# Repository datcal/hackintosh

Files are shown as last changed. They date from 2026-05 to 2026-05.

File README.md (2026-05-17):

# Hackintosh

A USB-tethered OLED companion device — Tinytosh-style retro-Mac chrome with live
animations — for showing clock, weather, air quality, currency rates, system
metrics, and now-playing media from your host PC.

## Hardware

- Seeed XIAO RP2040
- 0.96" SSD1306 128x64 I2C OLED at `0x3C`
- 2 momentary push buttons

For full wiring details, pin map, circuit diagram, and 4-pin button anatomy,
see **[docs/HARDWARE.md](docs/HARDWARE.md)**.

## Layout

```
firmware/   Arduino C++ for the XIAO RP2040 — receives 1024-byte framebuffers
            over USB-CDC and blits them; sends button events back.
host/       Go application — fetches data, renders 1-bit 128x64 framebuffers at
            30 FPS, streams them over the serial port.
scripts/    Build scripts (Windows .ps1, macOS .sh) for host + firmware + dev.
dist/       Build outputs (gitignored).
```

## Quick start

**Build the host:**
- Windows: `.\scripts\build-host.ps1`
- macOS:   `./scripts/build-host.sh`

**Build + flash the firmware in one shot** (recommended once your board is alive):
- Windows: `.\scripts\flash-firmware.ps1`
- macOS:   `./scripts/flash-firmware.sh`

This compiles + uploads via the 1200-baud auto-reset trick — no button presses on the board.

**First flash** (or recovery when firmware is unresponsive):
- Build only: `.\scripts\build-firmware.ps1` / `./scripts/build-firmware.sh`
- Then **double-tap the XIAO's RESET** and drag `dist/hackintosh.uf2` onto the `RPI-RP2` drive.

For one-time `arduino-cli` setup and troubleshooting, see **[docs/FLASHING.md](docs/FLASHING.md)**.

**Run without hardware (browser simulator):**
- Windows: `.\scripts\dev-host.ps1 --simulate=:8080`
- macOS:   `./scripts/dev-host.sh --simulate=:8080`

Open <http://localhost:8080> in a browser. You'll see a styled XIAO+OLED device
with the full UI streaming at 30 FPS via Server-Sent Events. The two on-screen
buttons (and keys `A`/`1`, `B`/`2`) feed presses back to the app exactly like
the real hardware. Long-press = hold for 700 ms.

The same flag works on the production binary:
```
dist\hackintosh.exe --simulate=:8080
dist/hackintosh     --simulate=:8080
```

**Probe a connected MCU:** `.\scripts\dev-host.ps1 --probe`

**Flags:** `--no-net` skips weather + currency · `--no-hw` skips system monitor
· `--no-media` skips the now-playing source · `--port=COM5` picks a specific
serial port.

## Install as a startup app

To have the host run automatically when you log in, with a menu-bar / tray
icon instead of a terminal window:

1. Build the host:
   - Windows: `./scripts/build-host.ps1`
   - macOS:   `./scripts/build-host.sh`
   - Linux:   `cd host && go build -o ../dist/hackintosh ./cmd/hackintosh`
2. Run the installer:

   ```
   ./dist/hackintosh install
   ```

   This copies the binary to a per-user location and registers it for
   autostart. No admin/sudo required.
3. The next time you log in, an icon appears in your system tray (Windows)
   or menu bar (macOS) or app tray (Linux). Right-click for: Open Simulator
   (only enabled in simulator mode), Restart, Quit.
4. Re-launch from your Start Menu / Applications folder / app menu after
   quitting, just like any other installed app.

To remove everything the installer added:

```bash
./dist/hackintosh uninstall
```

After making code changes, rebuild and run `./dist/hackintosh install`
again. It is idempotent and overwrites the previous binary.

### Linux note: system trays in GNOME

GNOME removed built-in tray support, so on stock GNOME the icon will not
appear without an extension like AppIndicator or TopIconsPlus. The host
still runs and connects to the device; only the menu is hidden.

### macOS note: Gatekeeper

The first run on macOS Catalina+ may trigger a Gatekeeper warning
("Hackintosh cannot be opened"). Right-click the app in Finder, choose Open,
or run `xattr -d com.apple.quarantine ~/Applications/Hackintosh.app` once.

## Controls

- **Button A** — Tea timer: tap to start a 3-minute countdown, tap again to pause/resume, long-press to reset. "TEA!" appears on the OLED when it expires.
- **Button B** — Cycle to the next screen (Clock → Weather → AQ → Currency → System → Media)
- **A + B together for 3 seconds** — Reboot into bootloader for over-the-USB firmware updates. The OLED briefly shows "BOOTLOAD ready to flash". Pair with `.\scripts\dev-host.ps1 --flash dist\hackintosh.uf2` for fully scripted updates.

## Documentation

- [docs/HARDWARE.md](docs/HARDWARE.md) — wiring, pin map, circuit diagram, button anatomy
- [docs/FLASHING.md](docs/FLASHING.md) — toolchain setup, firmware build, UF2 upload, troubleshooting

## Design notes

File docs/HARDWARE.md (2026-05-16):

# Hardware

Wiring, pin map, and physical assembly for Hackintosh.

## Parts list

| Part | Notes |
|---|---|
| Seeed XIAO RP2040 | The microcontroller. RP2040 chip, USB-C, no WiFi/BT. |
| 0.96" SSD1306 OLED, 128x64, I2C | Adafruit / generic. I2C address `0x3C`. |
| 2 momentary push buttons | 4-pin tactile style works (only 2 of the 4 pins are needed). |
| USB-C cable | Must be a *data* cable — many charge-only cables won't enumerate. |
| Optional: 2 x ~10kΩ resistors | NOT needed when using `INPUT_PULLUP` in firmware. |

## Pin assignments

The XIAO RP2040 has **silkscreen labels** (`D0`–`D10`) which are different from
the internal **GPIO numbers** (`GP0`–`GP29`). When wiring, use the silkscreen
labels — that's what's printed on the board next to each pin.

| Function | Silkscreen | Internal GPIO | Notes |
|---|---|---|---|
| OLED SDA | **D4** | GP6 | I2C data |
| OLED SCL | **D5** | GP7 | I2C clock |
| Button A | **D0** | GP26 | INPUT_PULLUP — buttons short to GND |
| Button B | **D1** | GP27 | INPUT_PULLUP — buttons short to GND |
| OLED VCC | **3V3** | — | 3.3 V supply |
| OLED GND | **GND** | — | shared with button GNDs |

## XIAO RP2040 pinout reference

Looking at the board with the **USB-C connector facing up**:

```
            +-------------+
            |    USB-C    |
            +--+-------+--+
        D0 -- *|       |* -- 5V
        D1 -- *|       |* -- GND
        D2 -- *|       |* -- 3V3
        D3 -- *|  XIAO |* -- D10
        D4 -- *| RP2040|* -- D9
        D5 -- *|       |* -- D8
              |       |* -- D7
              +-------+* -- D6
```

## Circuit diagram

```
                                 SSD1306 OLED 128x64
                                 +----+----+----+----+
                                 |GND |VCC |SCL |SDA |
                                 +-+--+-+--+-+--+-+--+
                                   |    |    |    |
                                   |    |    |    |
                       +-----------+    |    |    +---- to D4 (SDA)
                       |        +-------+    +---- to D5 (SCL)
                       |        |    +---- to 3V3
                       |        |    |
                       |        |    |
                      GND      3V3   |  (already routed via the OLED rail)
                       (shared GND rail with both buttons)

                       +----------------------+
                       |  XIAO RP2040         |
                       |  (USB-C on top)      |
                       |                      |
                  D0 --|                      |-- 5V
                  D1 --|                      |-- GND (shared GND rail)
                  D2 --|                      |-- 3V3 (powers OLED)
                  D3 --|                      |-- D10
                  D4 --| (OLED SDA)           |-- D9
                  D5 --| (OLED SCL)           |-- D8
                       |                      |
                       +----------------------+
                        ^                  ^
                        |                  |
                       D0                 D1
                        |                  |
            +----- BUTTON A -----+   +----- BUTTON B -----+
            |                    |   |                    |
            |  PIN 1 *    * PIN 2|   |  PIN 1 *    * PIN 2|
            |          X         |   |          X         |
            |  PIN 3 *    * PIN 4|   |  PIN 3 *    * PIN 4|
            +----+-----------+---+   +----+-----------+---+
                 |           |            |           |
              (to D0)     (to GND)     (to D1)     (to GND)
                 |           |            |           |
                 +-----------+------------+-----------+
                             |
                             v
                            GND (any GND pin on the XIAO)
```

## 4-pin tactile button anatomy

The 4 pins of a typical tactile button only correspond to **2 electrical
contacts**. Pins on the same side of the body are internally bridged with a
metal bar at all times — even when the button isn't pressed. Pressing the
cap closes a contact between the two sides.

```
          +---------------------+
          |                     |
   PIN 1 *|@           @        |* PIN 2
          |                     |
          |        [cap]        |
          |                     |
   PIN 3 *|@           @        |* PIN 4
          |                     |
          +---------------------+

  Always connected:
    PIN 1 --- PIN 3       (one internal side bar)
    PIN 2 --- PIN 4       (the other internal side bar)

  When pressed, the gap closes — now all four are connected.
```

**Rule of thumb:** pick any pin on the LEFT side and any pin on the RIGHT
side. Those are your "switch terminals." Diagonal (PIN 1 + PIN 4) is the
safest choice because they're guaranteed to be on opposite sides.

If your multimeter shows all 4 pins connected when pressed, your button
is healthy — that's expected behavior.

## How the active-LOW input works

The firmware configures Button A and Button B as `INPUT_PULLUP`. This
activates the RP2040's built-in ~50kΩ pull-up resistor on each GPIO, so:

```
Button NOT pressed:                Button PRESSED:

  3V3 --[ ~50kΩ pull-up ]--+         3V3 --[ ~50kΩ pull-up ]--+
                           |                                  |
                          GPIO  (reads HIGH ~ 3.3V)           GPIO  (reads LOW ~ 0V)
                           |                                  |
                          (open switch)                      (closed switch)
                           |                                  |
                          GND                                GND
```

In firmware (see `buttons.cpp`), `digitalRead(pin) == LOW` means "pressed."

## Why you don't need the external resistors

If your buttons came bundled with separate resistors, they were intended
for the **external pull-up** wiring pattern: GPIO -> 10kΩ -> 3V3, plus GPIO ->
button -> GND. With `INPUT_PULLUP` in firmware, the resistor is internal —
the external one becomes redundant.

You can wire the externals too if you want — it doesn't hurt, just makes the
input slightly stiffer against electrical noise. To use the externals
instead of the internal pull-up, change `INPUT_PULLUP` to `INPUT` in
`firmware/hackintosh/buttons.cpp:begin()`.

## Display orientation (mounting it upside-down)

If you physically mount the OLED upside-down, set this in
`firmware/hackintosh/config.h`:

```cpp
constexpr bool OLED_FLIP_180 = true;
```

This sends two override commands to the SSD1306 during init (`SEGREMAP` +
`COMSCANINC`) that rotate the display 180° in hardware. The host doesn't
need to know — every screen, splash, and animation comes out the right way
up. Set it back to `false` if you flip the mounting.

## Power budget

| Component | Typical | Max |
|---|---|---|
| RP2040 idle | ~15 mA | ~50 mA |
| SSD1306 OLED, all pixels off | ~5 mA | — |
| SSD1306 OLED, all pixels on | — | ~25 mA |
| Total at typical usage | ~25 mA | ~75 mA |

All well under USB's 500 mA budget. No need for an external supply.

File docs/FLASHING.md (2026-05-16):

# Flashing the firmware

How to compile and upload the Arduino firmware to your XIAO RP2040.

The RP2040 uses **UF2 (USB Flashing Format)**, which means you don't need
`avrdude`, `esptool`, or any traditional uploader — you just **copy a file
onto a USB drive that appears when you put the board into bootloader mode**.

Three ways to do it, in order of how nice they are once your firmware is
working:

1. **Hold A+B on the device for 3 seconds, then auto-copy from Go** —
   the cleanest path. Your application buttons trigger the reboot, the Go
   tool watches for the bootloader drive and copies the new firmware over.
   Zero physical RESET/BOOT button presses, fully scripted, works on
   Windows + macOS + Linux. See "Option 0" below.
2. **`arduino-cli` 1200-baud auto-upload** — works if your firmware is
   running and responsive. Compile + upload in one script.
3. **Manual double-tap RESET** — required for the very first flash (before
   any firmware exists) or if your current firmware is unresponsive.

## One-time toolchain setup

The Go host doesn't need anything beyond Go itself, but the firmware needs
the Arduino CLI plus the RP2040 board package and two display libraries.

```powershell
# 1. Install arduino-cli
winget install ArduinoSA.CLI
# (on macOS:  brew install arduino-cli)

# 2. Add the community RP2040 board package (Earle Philhower's core)
arduino-cli core update-index --additional-urls https://github.com/earlephilhower/arduino-pico/releases/download/global/package_rp2040_index.json
arduino-cli core install rp2040:rp2040 --additional-urls https://github.com/earlephilhower/arduino-pico/releases/download/global/package_rp2040_index.json

# 3. Install the OLED libraries
arduino-cli lib install "Adafruit GFX Library" "Adafruit SSD1306"
```

To verify the install succeeded:

```powershell
arduino-cli core list
# Should list:  rp2040:rp2040  <version>  arduino-pico

arduino-cli board listall xiao
# Should list:  Seeed XIAO RP2040  rp2040:rp2040:seeed_xiao_rp2040
```

The RP2040 board package is ~150 MB (it bundles a full GCC cross-compiler
for ARM Cortex-M0+). This is a one-time download.

## Build the .uf2

From the project root:

```powershell
.\scripts\build-firmware.ps1
```

On macOS / Linux:

```bash
./scripts/build-firmware.sh
```

This invokes `arduino-cli compile` with the right FQBN (`rp2040:rp2040:seeed_xiao_rp2040`),
compiles all the `.ino` and `.cpp` files under `firmware/hackintosh/`,
and writes `dist/hackintosh.uf2`.

Typical output size: 30–80 KB.

## Option 0 — A+B hold (3 sec) + Go auto-copy (recommended)

This is the smoothest workflow once the device is alive. The XIAO's tiny
on-board RESET and BOOT buttons are never touched.

### How it works

1. The firmware watches both application buttons (A on D0, B on D1). When
   it sees them held simultaneously for **3 seconds**, it briefly draws a
   "BOOTLOAD ready to flash" panel on the OLED, then calls
   `rp2040.rebootToBootloader()` — a soft reset into the mask-ROM bootloader.
2. The `RPI-RP2` mass-storage drive appears on your computer within ~500ms.
3. The Go host's `--flash` mode polls for that drive cross-platform
   (checking for the `INFO_UF2.TXT` marker file the bootloader always
   writes) and copies your new `dist\hackintosh.uf2` onto it.
4. The bootloader detects the .uf2 write, flashes it to internal flash, and
   reboots into the new firmware. Total elapsed: ~5-8 seconds.

### Step by step

**Terminal 1** — build the new firmware:

```powershell
.\scripts\build-firmware.ps1
```

**Terminal 2** — start the auto-flash watcher:

```powershell
.\scripts\dev-host.ps1 --flash dist\hackintosh.uf2
```

On macOS / Linux:

```bash
./scripts/dev-host.sh --flash dist/hackintosh.uf2
```

You'll see:

```text
flash: waiting for RPI-RP2 drive — hold A+B on the device for 3 seconds...
```

**On the device**: press and hold A and B together. After 3 seconds the
OLED briefly shows a bordered "BOOTLOAD ready to flash" panel — that's
your visual confirmation the combo registered. You can release the buttons
now; the board has already triggered the reboot.

The Go tool will then print:

```text
flash: found D:\, copying dist\hackintosh.uf2 (78420 bytes)...
flash: done — the board will reboot into the new firmware momentarily.
```

That's it. No physical RESET or BOOT button presses. By default the
watcher waits up to 60 seconds for the drive (configurable with
`--flash-timeout=N`).

### What if A+B doesn't work?

The A+B combo runs inside `buttons.cpp::poll()`, which is part of your
firmware's main loop. If your firmware is **crashing or unresponsive**,
that loop never runs and the combo never fires. In that case, fall back to
Option 1 (still software-driven, via arduino-cli's 1200-baud trick) or
Option 2 (manual double-tap RESET).

The hierarchy of escalating recovery:

| Firmware state | Use |
|---|---|
| Healthy + responsive | Option 0 (A+B for 3s + `--flash`) |
| Responds to serial but A+B handler broken | Option 1 (`.\scripts\flash-firmware.ps1`) |
| Crashing, no USB-CDC | Option 2 (double-tap RESET, drag .uf2 manually) |
| Bricked completely | Option 2 with the BOOT-button-hold variant |

## Option 1 — Automatic (compile + upload, no buttons)

Once you've successfully flashed the board at least once and the firmware
is running normally, you can use the one-shot script:

```powershell
.\scripts\flash-firmware.ps1
```

On macOS / Linux:

```bash
./scripts/flash-firmware.sh
```

This compiles the firmware AND uploads it via the **1200-baud reset trick**
(see "How it works" below). No button presses on the board are required.
The whole sequence takes ~5 seconds:

```text
Scanning for connected RP2040 board...
Flashing via COM5 (will reboot the board automatically)...

Sketch uses 88340 bytes (4%) of program storage space...
Performing 1200-bps touch reset on serial port COM5
Waiting for upload port...
Upload port found on COM5
Loading into Flash: [==============================] 100%
The device was reset

Done — firmware running. Test with: .\scripts\dev-host.ps1
```

If the script can't auto-detect your port, run `arduino-cli board list` to
see the right name and pass it explicitly:

```powershell
.\scripts\flash-firmware.ps1 -Port COM5
```

```bash
./scripts/flash-firmware.sh /dev/cu.usbmodem1101
```

### How the 1200-baud reset trick works

When `arduino-cli` opens the USB-CDC serial port at exactly **1200 baud**,
the arduino-pico core in your running firmware treats this as a magic
"reboot into bootloader" signal:

1. arduino-cli opens `COM5` at 1200 bps, briefly.
2. Your running firmware's USB-CDC handler sees the unusual baud rate, stores
   a magic value in SRAM, and triggers a watchdog reset.
3. The RP2040's mask ROM bootloader reboots, sees the magic value, and
   stays in BOOTSEL mode instead of launching the firmware.
4. The `RPI-RP2` drive appears.
5. arduino-cli copies the new .uf2 onto the drive.
6. The board reboots into the new firmware.

This is the same trick used by Arduino Leonardo / Pro Micro / Teensy and
many other boards — it lets you flash without ever touching the physical
RESET button. The catch: it only works if your *currently running* firmware
is responsive enough to receive the 1200-baud signal. If you've bricked
the board with crashing firmware, the host-side script will time out
waiting for the `RPI-RP2` drive to appear; fall back to Option 2 below.

## Option 2 — Manual upload (the first time, or when stuck)

Plug the XIAO into your computer with a **USB-C data cable**. Then choose
one of two methods:

### Method A — double-tap RESET (normal path)

1. With the XIAO plugged in, **double-tap the small RESET button** on the
   board (next to the USB connector).
2. A USB drive named `RPI-RP2` appears in your file explorer.
3. **Drag `dist\hackintosh.uf2` onto that drive.**
4. The drive disappears and the board reboots — your firmware is running.

### Method B — hold BOOT during plug-in (rescue path)

Use this when Method A doesn't work (e.g., if the previously-flashed
firmware crashes immediately and never gets to the point where a double-tap
can trigger the bootloader):

1. Unplug the XIAO.
2. **Hold the BOOT button** while plugging the USB cable back in. Keep it
   held for a second after it's plugged in.
3. The `RPI-RP2` drive appears.
4. Drag `dist\hackintosh.uf2` onto it.

## Verify the firmware is alive

```powershell
# List ports — your XIAO should show up as a COM... or /dev/cu.usbmodem... entry:
.\scripts\dev-host.ps1 --list-ports

# Test the USB-CDC link with PING/PONG and live button events:
.\scripts\dev-host.ps1 --probe
```

You should see something like:

```
auto-picked port: COM5
2026/05/16 17:09:35 probe: waiting for events. Press Ctrl-C to exit.
2026/05/16 17:09:35 PONG  (RTT 0s)
2026/05/16 17:09:37 PONG  (RTT 0s)
2026/05/16 17:09:42 BUTTON A press
2026/05/16 17:09:42 BUTTON A release
```

"RTT 0s" is normal — USB-CDC round-trip is in the hundreds of nanoseconds,
which my display rounds down to 0. The OLED will show the animated radar
"searching for host..." splash because `--probe` doesn't send any
framebuffers — that's the firmware's correct fallback behavior.

To see the actual UI:

```powershell
.\scripts\dev-host.ps1
```

(No flags. This runs the full app with all data sources active.)

## Troubleshooting

| Symptom | Fix |
|---|---|
| `arduino-cli: command not found` | Toolchain setup didn't finish — re-run the winget/brew install and restart your shell. |
| `Adafruit_SSD1306.h: No such file` | `arduino-cli lib install "Adafruit SSD1306"`. |
| Double-tap RESET does nothing | Use Method B — the existing firmware may be unresponsive. |
| `RPI-RP2` drive doesn't appear | Try a different USB cable. Many USB-C cables are charge-only. |
| OLED stays black after flash | Check wiring: SDA on D4, SCL on D5, OLED VCC on 3V3 (not 5V). Confirm the address — some breakouts ship at `0x3D` instead of `0x3C`; change `OLED_ADDR` in `firmware/hackintosh/config.h`. |
| `--probe` shows no PONG | The host might have grabbed the wrong serial port. Try `--list-ports`, identify the XIAO's actual port name, and use `--probe --port=COM6` (or whatever). |
| Display is upside-down | Set `OLED_FLIP_180 = true` in `firmware/hackintosh/config.h` and re-flash. |
| Garbled pixels or partial screens | If you've changed the protocol, host and firmware versions may be mismatched — rebuild both and re-flash. |
| Compile error about a missing function or symbol | Make sure you rebuilt `dist/hackintosh.uf2` after editing the firmware. The build script doesn't auto-watch files. |

## How UF2 works (educational background)

The RP2040 has a tiny **mask-ROM bootloader** built into the silicon. It
runs the moment the chip powers on and decides whether to launch your
firmware or expose the chip as a USB mass-storage device.

The decision is made in <500 ms after power-on:

- If `RUN` (the BOOT pin) is held LOW during reset → enter bootloader mode
  (exposes `RPI-RP2` drive).
- Otherwise → launch firmware at flash address `0x10000000`.

The "double-tap RESET" trick works because the RP2040 also watches for a
**second reset within ~500 ms of the first one**, and re-enters the
bootloader if it sees one. This is purely a hardware feature — it works
even if your firmware crashes immediately, because the second RESET pulse
bypasses everything.

UF2 itself is a tiny file format invented by Microsoft for the BBC micro:bit.
Each .uf2 file is a series of 512-byte blocks; each block contains 256 bytes
of payload plus metadata saying *where in flash* it should land. When you
drag a .uf2 onto the `RPI-RP2` drive, the bootloader reads each block,
copies its payload to the indicated flash address, and reboots when done.
There's no protocol — you really are just copying a file.

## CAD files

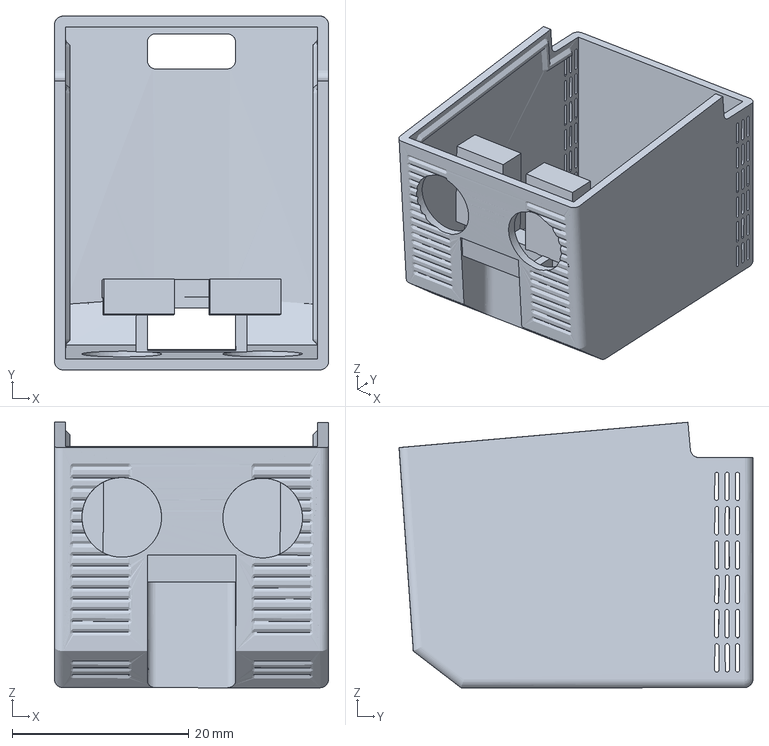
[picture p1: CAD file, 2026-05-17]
3d/Hackintosh.3mf
31.0 x 40.0 x 30.0 mm

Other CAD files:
3d/Hackintosh.gcode.3mf
3d/Hackintosh-push-button-cap.f3d
3d/Hackintosh.f3d

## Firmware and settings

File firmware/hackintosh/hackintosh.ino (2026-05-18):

// hackintosh firmware
//
// Receives 128x64 1-bit framebuffers over USB-CDC at ~30 FPS and blits them
// to the SSD1306. Sends button events back to the host. Shows a self-drawn
// disconnect splash if the host stops sending frames for >3 s.
//
// When disconnected, button A drives a native 3-minute tea timer that
// renders directly to the OLED without needing the host.

#include <Arduino.h>
#include "config.h"
#include "display.h"
#include "transport.h"
#include "buttons.h"
#include "timer.h"

static bool displayReady = false;

void setup() {
    Serial.begin(SERIAL_BAUD);
    displayReady = display::begin();
    if (displayReady) display::drawBootSplash();
    buttons::begin();
}

void loop() {
    transport::poll();
    buttons::poll();

    if (!displayReady) return;

    const uint32_t now = millis();

    // Consume button A events every loop so they don't queue up.
    // When disconnected, route them to the firmware timer.
    // When connected, the host handles the tea timer via framebuffer.
    const bool aPressEvent = buttons::consumeAPress();
    const bool aLongEvent  = buttons::consumeALong();
    if (!transport::isConnected()) {
        if (aPressEvent) timer::tap();
        if (aLongEvent)  timer::reset();
    }

    timer::tick(now);

    if (transport::consumeNewFrame()) {
        display::blitFrame(transport::lastFrame());
        return;
    }

    // No fresh frame this iteration. If we're still inside the connected
    // window, just leave the last frame on the OLED. If we've lost the host,
    // update the display at ~5 fps so the screen never feels dead.
    if (!transport::isConnected()) {
        static uint32_t lastDrawMs = 0;
        if (now - lastDrawMs >= 200) {
            lastDrawMs = now;
            if (timer::getState() != timer::IDLE) {
                display::drawTimerDisplay(
                    timer::getState(),
                    timer::remainingMs(now),
                    timer::progress(now),
                    now
                );
            } else {
                display::drawDisconnectSplash(now);
            }
        }
    }
}

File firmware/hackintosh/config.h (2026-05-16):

#pragma once

// ===== Pin map (Seeed XIAO RP2040) =====
//
// The XIAO has two parallel pin namings:
//   - "Dx" labels printed on the silkscreen (what you see when wiring)
//   - "GPxx" raw RP2040 GPIO numbers (what the chip actually addresses)
//
// We use the D0..D10 macros from the arduino-pico Seeed variant so the
// source matches the board. The compiler resolves these to GPIO numbers:
//
//   D0 -> GP26   D1 -> GP27   D4 -> GP6   D5 -> GP7
//
// Wire your hardware to the pins labeled D0/D1/D4/D5 on the board.
constexpr uint8_t PIN_SDA      = D4;  // OLED SDA  -> silkscreen "D4" (GP6)
constexpr uint8_t PIN_SCL      = D5;  // OLED SCL  -> silkscreen "D5" (GP7)
constexpr uint8_t PIN_BTN_A    = D0;  // Button A  -> silkscreen "D0" (GP26)
constexpr uint8_t PIN_BTN_B    = D1;  // Button B  -> silkscreen "D1" (GP27)

// ===== OLED =====
constexpr uint8_t  OLED_W       = 128;
constexpr uint8_t  OLED_H       = 64;
constexpr uint8_t  OLED_ADDR    = 0x3C;
constexpr uint16_t FRAME_BYTES  = (uint16_t)(OLED_W * OLED_H / 8);  // 1024

// Set true if the OLED is mounted upside-down. Toggles SSD1306's SEGREMAP +
// COM-scan-direction registers so the chip rotates everything 180 degrees in
// hardware. No software framebuffer flipping needed — the host can keep
// drawing pixel (0,0) at the "logical" top-left.
constexpr bool OLED_FLIP_180    = true;

// ===== Serial transport =====
constexpr uint32_t SERIAL_BAUD          = 115200;  // ignored by USB-CDC, but harmless
constexpr uint8_t  PROTO_MAGIC_0        = 0xAA;
constexpr uint8_t  PROTO_MAGIC_1        = 0x55;
constexpr uint32_t DISCONNECT_TIMEOUT_MS = 3000;

// Inbound frame types (host -> MCU)
constexpr uint8_t TYPE_FRAME      = 0x01;
constexpr uint8_t TYPE_BRIGHTNESS = 0x02;
constexpr uint8_t TYPE_PING       = 0x03;

// Outbound frame types (MCU -> host)
constexpr uint8_t TYPE_BUTTON     = 0x81;
constexpr uint8_t TYPE_PONG       = 0x82;
constexpr uint8_t TYPE_LOG        = 0x83;

// Button events
constexpr uint8_t BTN_ID_A        = 0;
constexpr uint8_t BTN_ID_B        = 1;
constexpr uint8_t BTN_EVT_PRESS   = 0;
constexpr uint8_t BTN_EVT_RELEASE = 1;
constexpr uint8_t BTN_EVT_LONG    = 2;

constexpr uint16_t BTN_DEBOUNCE_MS  = 15;
constexpr uint16_t BTN_LONGPRESS_MS = 700;

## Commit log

2026-05-17 feat: wire tray to main
2026-05-17 fix: hide child powershell windows
2026-05-17 fix: add 3d files
    [Hackintosh-push-button-cap.f3d, Hackintosh.3mf, Hackintosh.f3d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]
